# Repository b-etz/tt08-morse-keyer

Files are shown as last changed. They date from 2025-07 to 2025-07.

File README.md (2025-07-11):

   

# Morse Keyer - A lightweight hardware (Verilog) keyer for CW training

- [Read the documentation for project](docs/info.md)

## What is Tiny Tapeout?

Tiny Tapeout is an educational project that aims to make it easier and cheaper than ever to get your digital and analog designs manufactured on a real chip.

To learn more and get started, visit https://tinytapeout.com.

## About this Verilog Project

Please see [docs/info.md](docs/info.md) for a description of this project. An application schematic is shown below.

This design is a CW keyer taking paddle (Iambic) inputs and outputting dits and dahs to a radio/LED/buzzer for training and play. WPM control and Iambic/Straight key selection are done with inputs 7:4 and 0:1, respectively. It also outputs active-high LED controls for a 7-segment display on the board. This design takes advantage of input dip switches and an output seven-segment display present on the demo PCB kit provided with most Tiny Tapeout orders. For more, see: [https://www.tinytapeout.com/specs/pcb/](https://www.tinytapeout.com/specs/pcb/)

If you'd like to use this HDL in your own system, be sure to check the I/O mappings shown in [src/project.v](src/project.v) and adjust accordingly.

The [cocotb](https://docs.cocotb.org/en/stable/index.html) testbench is admittedly sparse. More rigorous testing has been performed with a Spartan 7 FPGA with no noticeable issues.

## Application Schematic for UIO PMOD Port

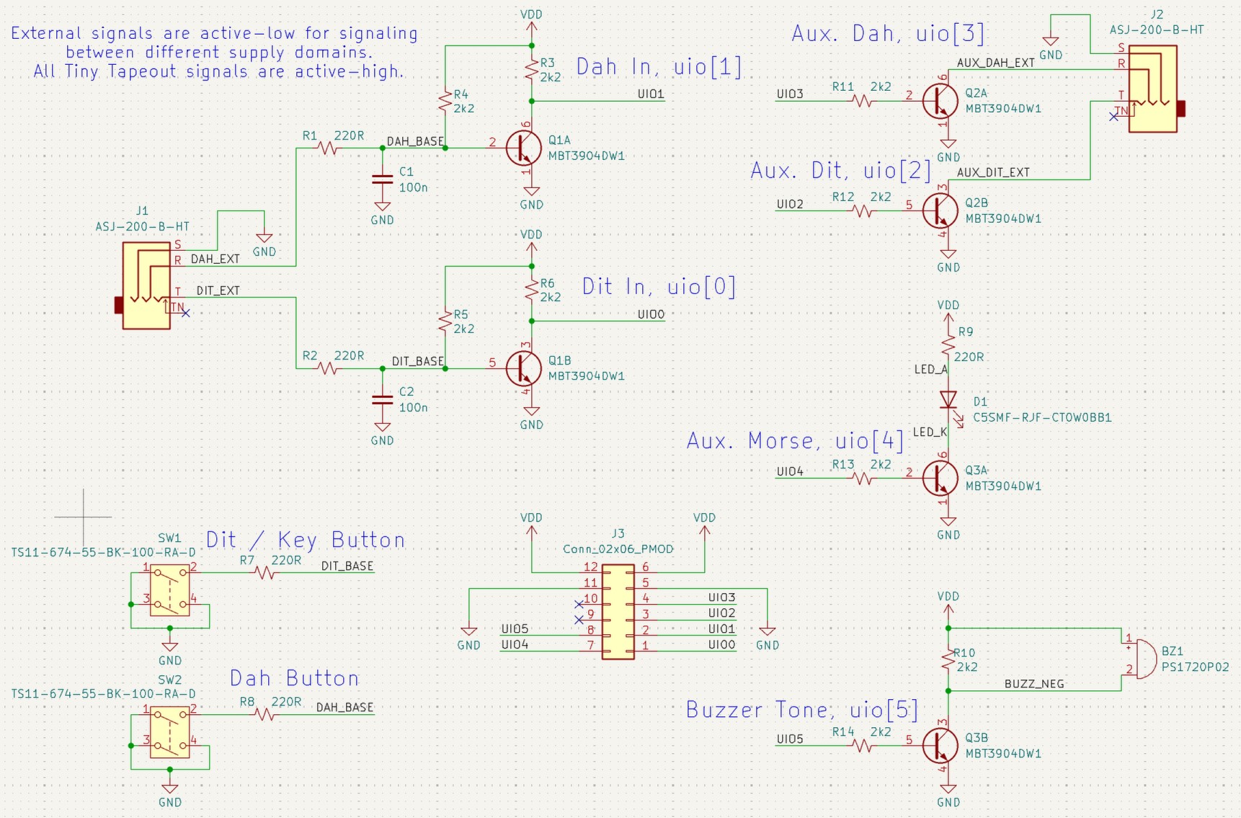
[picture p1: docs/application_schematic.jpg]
KiCad Application Schematic - 2025 Jul 11


## Example Breakout PCB Based on Schematic

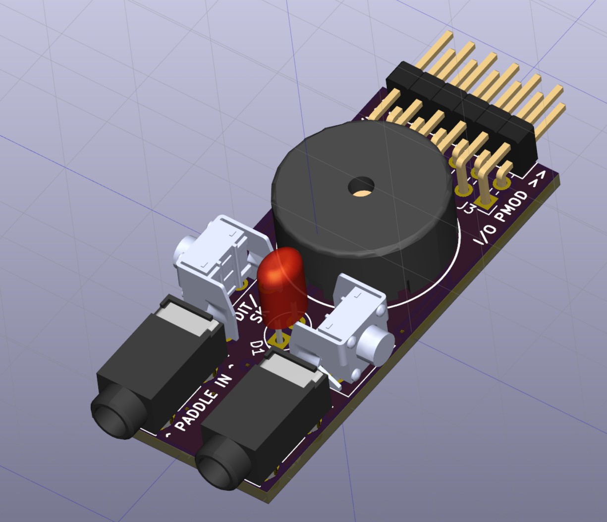
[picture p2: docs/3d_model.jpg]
KiCad 3D Render - 2025 Jul 11


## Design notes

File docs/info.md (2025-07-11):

<!---

This file is used to generate your project datasheet. Please fill in the information below and delete any unused
sections.

You can also include images in this folder and reference them in the markdown. Each image must be less than
512 kb in size, and the combined size of all images must be less than 1 MB.
-->

## How it works

Morse Keyer takes a paddle-type dit/dah signal (io[0:1]) and converts it to an auxilliary Morse code output (io[4]) and a buzzer tone (io[5]).
The design outputs auxilliary dit/dah signals (io[2:3]) to send to other gear, like a radio.
Additionally, it outputs to the demonstration board's seven-segment display (out[7:0]) to reveal the character you just completed as you key.

To use a straight-key input (or press a single button to key Morse code) set in[0] HIGH. For Iambic paddles, set in[0] LOW.
To use Iambic keying type A, set in[1] LOW. For Iambic-B, set in[1] HIGH. (https://ag6qr.net/index.php/2017/01/06/iambic-a-or-b-or-does-it-matter/)
WPM control is set between 7 WPM and ~100 WPM with in[7:4] via the demo board dip switches.
The timing element in this system divides the system clock first with a 512x prescaler, then feeds it into the variable delay below:

| Control [7:4] | WPM | Clocks | Timer Preset |
| ---: | :---: | :----: | :---: |
| 4'b0000 | 110.3 | 255 | 12'b000011111111 |
| 4'b0001 | 55.0  | 511 | 12'b000111111111 |
| 4'b0010 | 36.7  | 767 | 12'b001011111111 |
| 4'b0011 | 27.5  | 1023 | 12'b001111111111 |
| 4'b0100 | 22.0  | 1279 | 12'b010011111111 |
| 4'b0101 | 18.3  | 1535 | 12'b010111111111 |
| 4'b0110 | 15.7  | 1791 | 12'b011011111111 |
| 4'b0111 | 13.7  | 2047 | 12'b011111111111 |
| 4'b1000 | 12.2  | 2303 | 12'b100011111111 |
| 4'b1001 | 11.0  | 2559 | 12'b100111111111 |
| 4'b1010 | 10.0  | 2815 | 12'b101011111111 |
| 4'b1011 | 9.2 | 3071 | 12'b101111111111 |
| 4'b1100 | 8.5 | 3327 | 12'b110011111111 |
| 4'b1101 | 7.9 | 3583 | 12'b110111111111 |
| 4'b1110 | 7.3 | 3839 | 12'b111011111111 |
| 4'b1111 | 6.9 | 4095 | 12'b111111111111 |

WARNING: The auxilliary Morse output MUST NOT be used as a raw radio TX control for a homemade radio. This is because the keying interface must control the transmitted wave shape to maintain acceptable RF bandwidth. Be a good RF neighbor. Always use the provided keyer inputs for your radio. These are typically provided with a 3.5mm TRS jack, with Sleeve = GND, Ring = Dah, and Tip = Dit/Straight.

Most radio systems use active-low / open-collector signaling to protect systems operating at various supply voltages. Please see the External Hardware section for recommendations.

## How to test

Set the input clock frequency to 12 MHz.
Set the dip switches (in[7:0]) on the dev board to the desired paddle setup and WPM rate.
Attach hardware like that shown in the External Hardware section to use.

## External hardware

For the best experience, and to use custom radio hardware and paddles, I recommend assembling a companion PCB affixed the bidirectional PMOD.

A /pcb/ directory accompanies the standard Tiny Tapeout directories with the KiCad files.

Please see the schematic below for a screenshot of the recommended application schematic:

KiCad Application Schematic - 2024 Sep 02

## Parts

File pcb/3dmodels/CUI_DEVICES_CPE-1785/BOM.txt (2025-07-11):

3DX_CUI_DEVICES_Supplier: CUI Devices
3DX_CUI_DEVICES_Description: 17 mm, 20 V, 85 dB, Through Hole, Piezo Audio Transducer Buzzer
3DX_CUI_DEVICES_Model Number: CPE-1785

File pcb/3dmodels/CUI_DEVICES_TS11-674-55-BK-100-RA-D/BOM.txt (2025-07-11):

3DX_CUI_DEVICES_Supplier: CUI Devices
3DX_CUI_DEVICES_Description: 6 x 7.4 mm, 5.5 mm Actuator Height, 100 gf, Black, Right Angle, Through Hole, SPST, Tactile Switch
3DX_CUI_DEVICES_Model Number: TS11-674-55-BK-100-RA-D

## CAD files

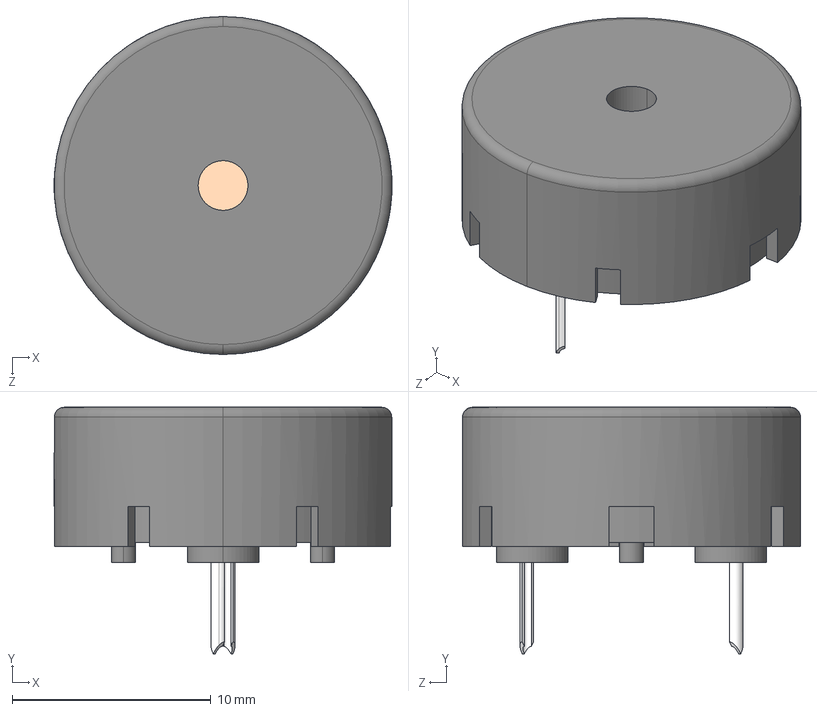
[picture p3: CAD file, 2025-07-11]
pcb/3dmodels/CUI_DEVICES_CPE-1785/CUI_DEVICES_CPE-1785.step
17.0 x 12.4 x 17.0 mm

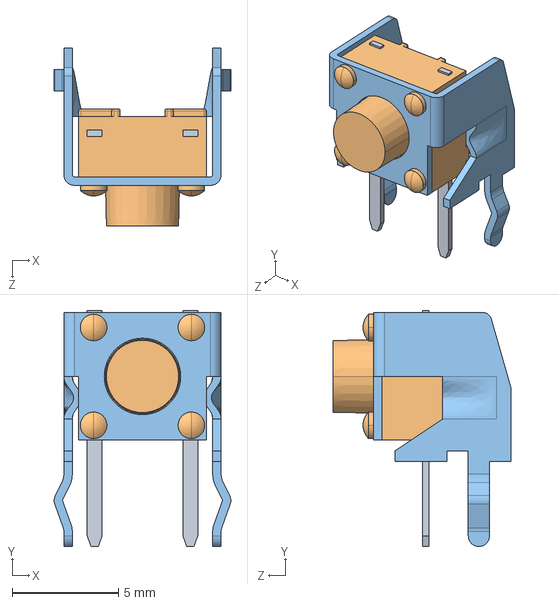
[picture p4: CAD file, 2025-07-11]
pcb/3dmodels/CUI_DEVICES_TS11-674-55-BK-100-RA-D/CUI_DEVICES_TS11-674-55-BK-100-RA-D.step
8.31 x 11.1 x 8.35 mm

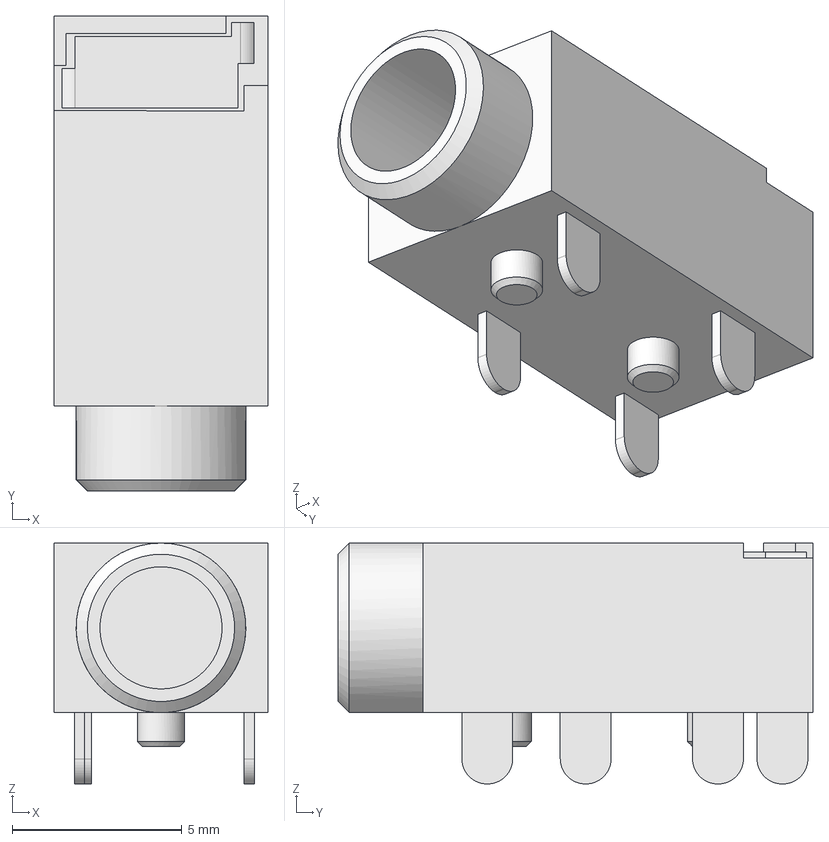
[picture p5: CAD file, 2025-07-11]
pcb/3dmodels/LIB_ASJ-200-B-HT/asj_200_b_ht_flipped.FCStd
6.30 x 14.0 x 7.10 mm

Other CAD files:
pcb/3dmodels/LIB_ASJ-200-B-HT/ASJ-200-B-HT.stp
pcb/3dmodels/LIB_ASJ-200-B-HT/ASJ-200-B-HT_mirrored.step

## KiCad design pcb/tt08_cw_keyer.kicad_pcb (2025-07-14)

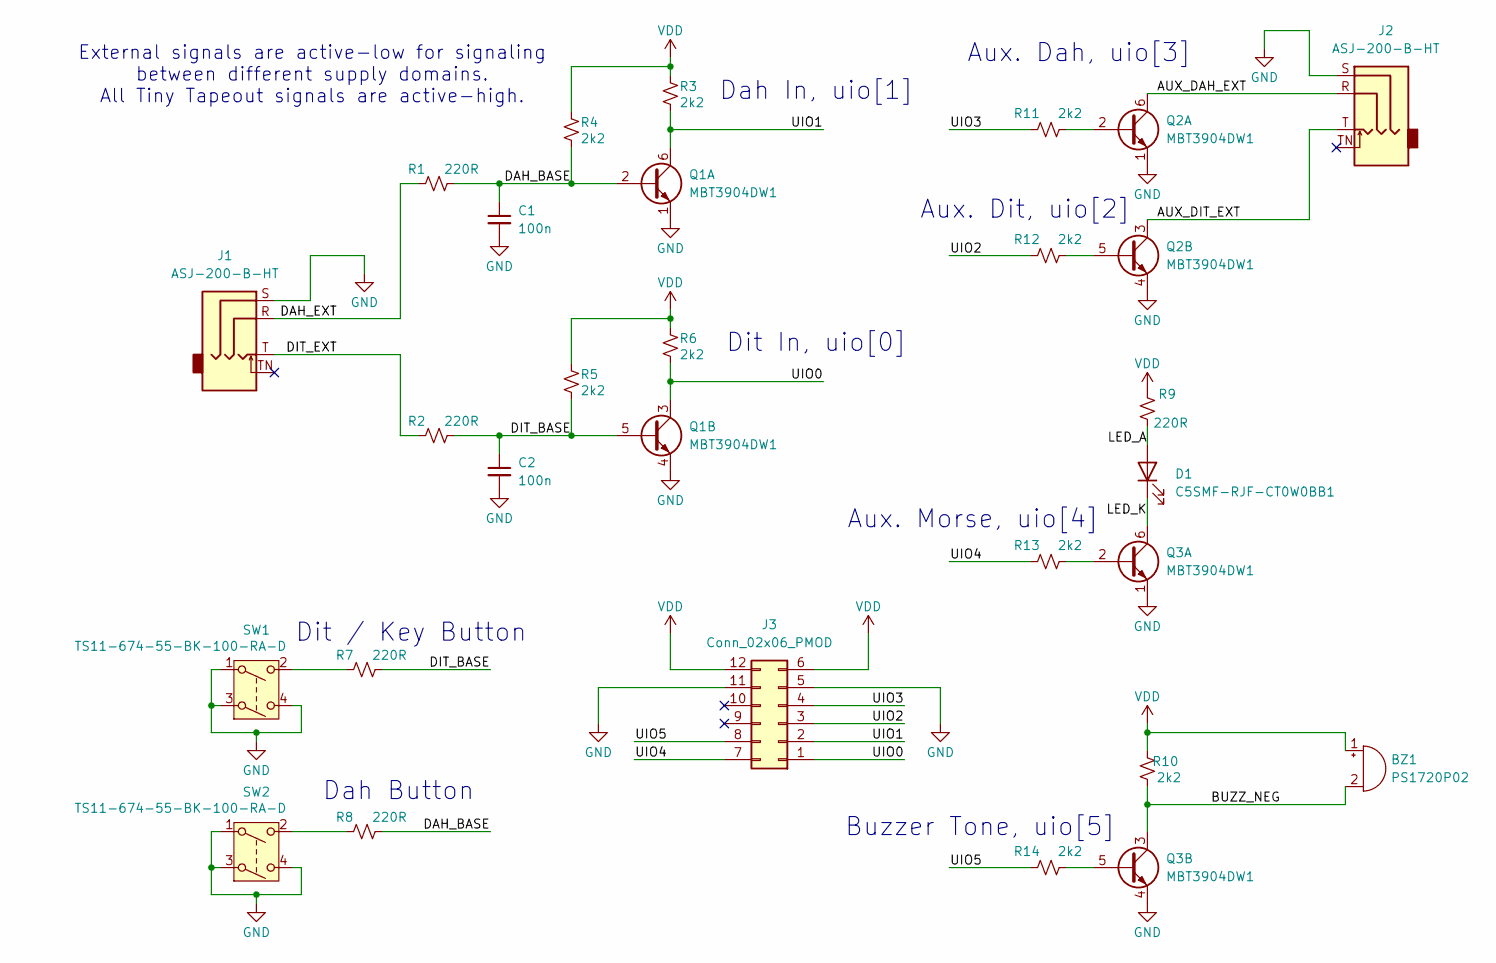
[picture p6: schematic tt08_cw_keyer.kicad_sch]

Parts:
BZ1: PS1720P02; Buzzer_TDK_PS1720P02
C1, C2: 100n; C_0805_2012Metric_Pad1.18x1.45mm_HandSolder
D1: C5SMF-RJF-CT0W0BB1; LED_Oval_W5.2mm_H3.8mm
J1, J2: ASJ-200-B-HT
J3: Conn_02x06_PMOD; PinHeader_2x06_P2.54mm_Horizontal_Flipped
Q1, Q2, Q3: MBT3904DW1; SOT-363_SC-70-6
R1, R2, R7, R8, R9: 220R; R_0805_2012Metric_Pad1.20x1.40mm_HandSolder
R3, R4, R5, R6, R10, R11, R12, R13, R14: 2k2; R_0805_2012Metric_Pad1.20x1.40mm_HandSolder
SW1, SW2: TS11-674-55-BK-100-RA-D

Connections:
/AUX_DAH_EXT: J2.R, Q2.6 (C1)
/AUX_DIT_EXT: J2.T, Q2.3 (C2)
/BUZZ_NEG: BZ1.2 (-), Q3.3 (C2), R10.1
/DAH_BASE: C1.1, Q1.2 (B1), R1.2, R4.1, R8.2
/DAH_EXT: J1.R, R1.1
/DIT_BASE: C2.1, Q1.5 (B2), R2.2, R5.1, R7.2
/DIT_EXT: J1.T, R2.1
/LED_A: D1.2 (A), R9.1
/LED_K: D1.1 (K), Q3.6 (C1)
/UIO0: J3.1, Q1.3 (C2), R6.1
/UIO1: J3.2, Q1.6 (C1), R3.1
/UIO2: J3.3, R12.2
/UIO3: J3.4, R11.2
/UIO4: J3.7, R13.2
/UIO5: J3.8, R14.2
GND: C1.2, C2.2, J1.S, J2.S, J3.5, J3.11, Q1.1 (E1), Q1.4 (E2), Q2.1 (E1), Q2.4 (E2), Q3.1 (E1), Q3.4 (E2), SW1.1, SW1.3, SW1.4, SW2.1, SW2.3, SW2.4
unnamed: Q2.2 (B1), R11.1
unnamed: Q2.5 (B2), R12.1
unnamed: Q3.2 (B1), R13.1
unnamed: Q3.5 (B2), R14.1
unnamed: R7.1, SW1.2
unnamed: R8.1, SW2.2
VDD: BZ1.1 (+), J3.6, J3.12, R3.2, R4.2, R5.2, R6.2, R9.2, R10.2

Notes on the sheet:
External signals are active-low for signaling between different supply domains. All Tiny Tapeout signals are active-high.
Dah In, uio[1]
Aux. Dah, uio[3]
Buzzer Tone, uio[5]
Dit In, uio[0]
Dit / Key Button
Aux. Dit, uio[2]
Dah Button
Aux. Morse, uio[4]

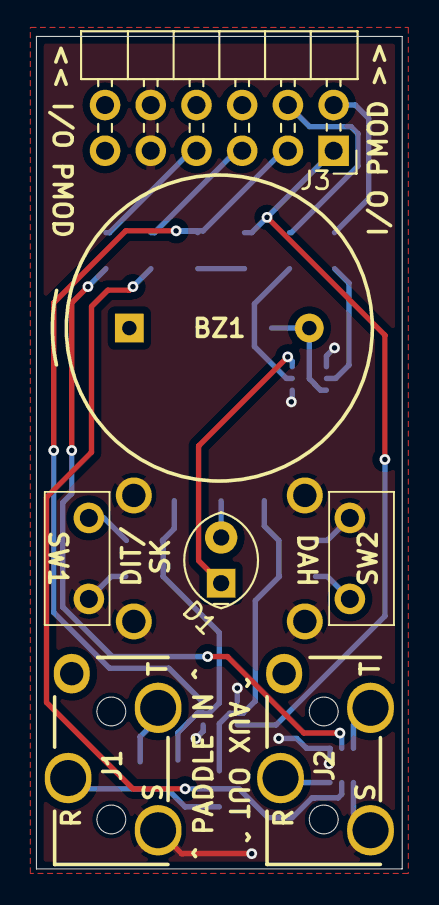
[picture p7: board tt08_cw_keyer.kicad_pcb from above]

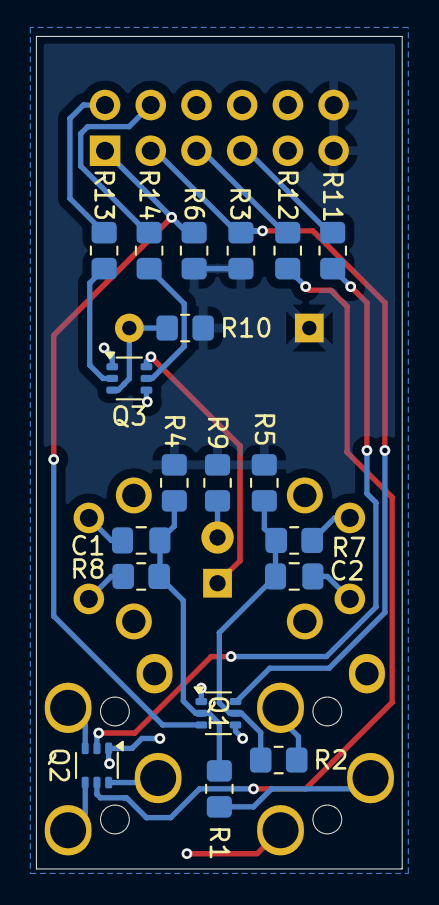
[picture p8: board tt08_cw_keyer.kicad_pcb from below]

Board: 2 copper layers, 20.3 x 46.2 mm, 26 parts (19 on the bottom side), 23 nets.

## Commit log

2025-07-11 Update with final PCB and 3D render, pending submission for SKY130A run
    [ASJ-200-B-HT.stp, ASJ-200-B-HT_mirrored.step, CUI_DEVICES_CPE-1785.step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]
2025-07-11 Update GL_TEST power rail definitions to TTSKY25a format
2025-07-14 Update PCB to correct DRC errors, unconventional audio jack pads, edge clearance
    [tt08_cw_keyer.kicad_pcb]
